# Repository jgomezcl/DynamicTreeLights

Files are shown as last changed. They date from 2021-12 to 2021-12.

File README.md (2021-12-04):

# Dynamic Tree Lights
Custom tree lights that react to changes in the environment lighting. Once a change is detected on an individual tree light it emits a white flash after a short delay followed by three more of random duration in random colors. These can also trigger nearby tree lights, so the flash propagates through the Christmas tree.

This project was inspired by CONSTELLACTION, an installation created by panGenerator for Copernicus Science Centre / Przemiany Festiwal 2013 (https://vimeo.com/76479685).

The PCBs are built around an Attiny84 microcontroller and require an ICSP to be programmed. I used an Arduino Nano with the sketch ArduinoISP.ino that can be found on the examples of the Arduino IDE.

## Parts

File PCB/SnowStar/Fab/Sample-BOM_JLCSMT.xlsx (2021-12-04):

Comment | Designator | Footprint | JLCPCB Part #（optional）
100n | C1 | Capacitor_SMD:C_0603_1608Metric | C14663
100n | C2 | Capacitor_SMD:C_0603_1608Metric | C14663
100n | C3 | Capacitor_SMD:C_0603_1608Metric | C14663
100n | C4 | Capacitor_SMD:C_0603_1608Metric | C14663
100n | C5 | Capacitor_SMD:C_0603_1608Metric | C14663
100n | C6 | Capacitor_SMD:C_0603_1608Metric | C14663
TX1812LB | D1 | SnowStar:LED_TX1812LB_TC2528RGB_2,4x2,7mm | C784561
TX1812LB | D2 | SnowStar:LED_TX1812LB_TC2528RGB_2,4x2,7mm | C784561
TX1812LB | D3 | SnowStar:LED_TX1812LB_TC2528RGB_2,4x2,7mm | C784561
TX1812LB | D4 | SnowStar:LED_TX1812LB_TC2528RGB_2,4x2,7mm | C784561
TX1812LB | D5 | SnowStar:LED_TX1812LB_TC2528RGB_2,4x2,7mm | C784561
TX1812LB | D6 | SnowStar:LED_TX1812LB_TC2528RGB_2,4x2,7mm | C784561
ICSP | J1 | Connector_PinHeader_2,54mm:PinHeader_2x03_P2,54mm_Vertical
Pow | J2 | Connector_PinHeader_2,54mm:PinHeader_1x02_P2,54mm_Vertical
Pow | J3 | Connector_PinHeader_2,54mm:PinHeader_1x02_P2,54mm_Vertical
SolderJumper_2_Open | JP1 | Jumper:SolderJumper-2_P1,3mm_Open_Pad1,0x1,5mm
10k | R1 | Resistor_SMD:R_0603_1608Metric | C25804
10k | R2 | Resistor_SMD:R_0603_1608Metric | C25804
10k | R3 | Resistor_SMD:R_0603_1608Metric | C25804
R_PHOTO | R4 | OptoDevice:R_LDR_5,1x4,3mm_P3,4mm_Vertical
R_PHOTO | R5 | OptoDevice:R_LDR_5,1x4,3mm_P3,4mm_Vertical
R_PHOTO | R6 | OptoDevice:R_LDR_5,1x4,3mm_P3,4mm_Vertical
10k | R7 | Resistor_SMD:R_0603_1608Metric | C25804
10k | R8 | Resistor_SMD:R_0603_1608Metric | C25804
ATtiny84-20SSU | U1 | Package_SO:SOIC-14_3,9x8,7mm_P1,27mm

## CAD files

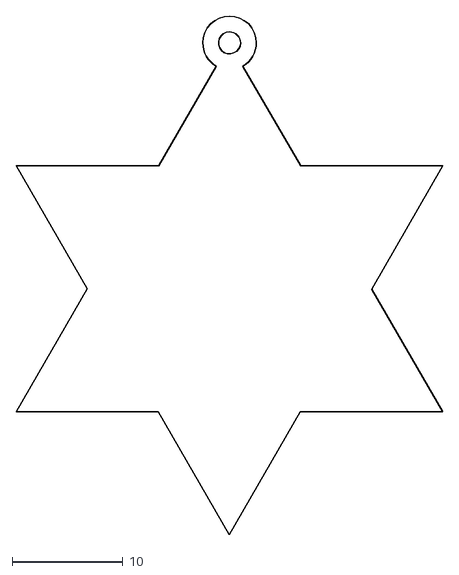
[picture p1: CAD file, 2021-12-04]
PCB/Drawings/SnowStarOutline.dxf
38.5 x 46.9

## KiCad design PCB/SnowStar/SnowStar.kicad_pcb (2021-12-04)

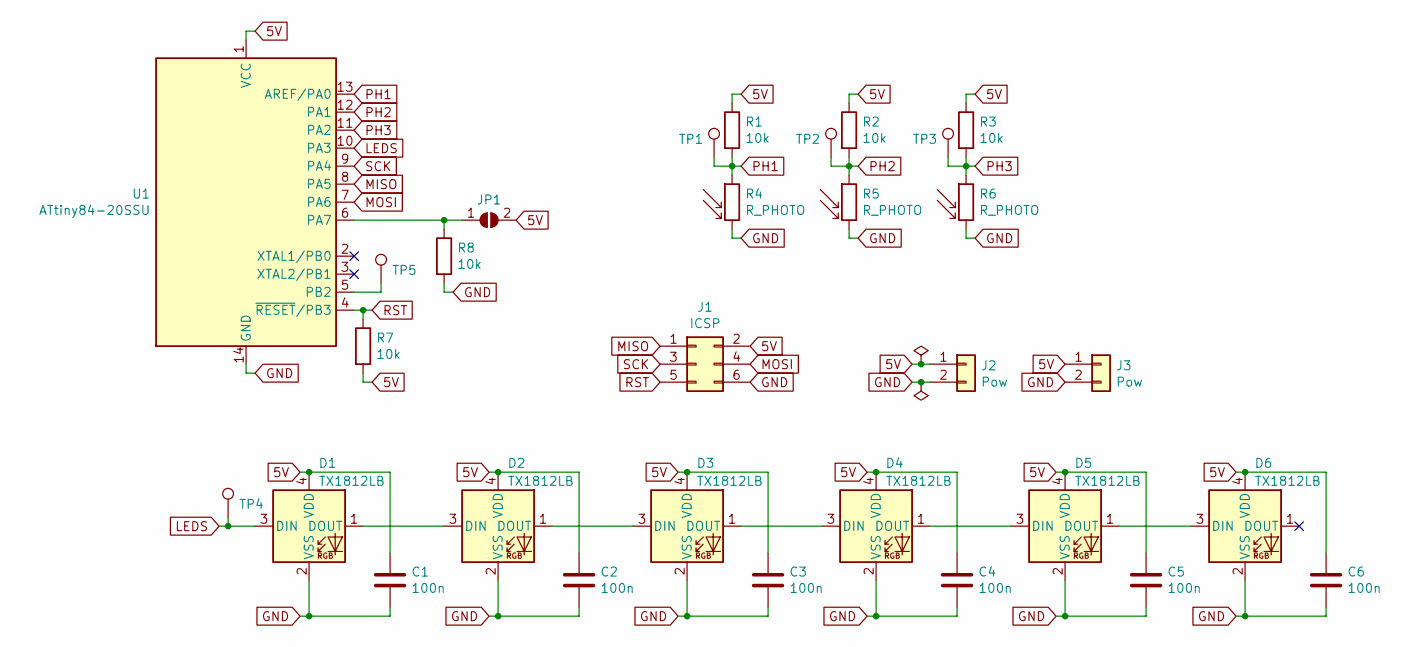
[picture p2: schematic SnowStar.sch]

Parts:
C1, C2, C3, C4, C5, C6: 100n; C_0603_1608Metric; LCSC Part # C14663
D1, D2, D3, D4, D5, D6: TX1812LB; LED_TX1812LB_TC2528RGB_2.4x2.7mm; LCSC Part # C784561
J1: ICSP; PinHeader_2x03_P2.54mm_Vertical
J2, J3: Pow; PinHeader_1x02_P2.54mm_Vertical
JP1: SolderJumper_2_Open; SolderJumper-2_P1.3mm_Open_Pad1.0x1.5mm
R1, R2, R3, R7, R8: 10k; R_0603_1608Metric; LCSC Part # C25804
R4, R5, R6: R_PHOTO; R_LDR_5.1x4.3mm_P3.4mm_Vertical
TP1, TP2, TP3, TP4, TP5: TestPoint; TestPoint_Pad_D1.5mm
U1: ATtiny84-20SSU; SOIC-14_3.9x8.7mm_P1.27mm

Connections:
5V: C1.1, C2.1, C3.1, C4.1, C5.1, C6.1, D1.4 (VDD), D2.4 (VDD), D3.4 (VDD), D4.4 (VDD), D5.4 (VDD), D6.4 (VDD), J1.2, J2.1, J3.1, JP1.2 (B), R1.1, R2.1, R3.1, R7.2, U1.1 (VCC)
GND: C1.2, C2.2, C3.2, C4.2, C5.2, C6.2, D1.2 (VSS), D2.2 (VSS), D3.2 (VSS), D4.2 (VSS), D5.2 (VSS), D6.2 (VSS), J1.6, J2.2, J3.2, R4.2, R5.2, R6.2, R8.2, U1.14 (GND)
LEDS: D1.3 (DIN), TP4.1, U1.10 (PA3)
MISO: J1.1, U1.8 (PA5)
MOSI: J1.4, U1.7 (PA6)
unnamed: D1.1 (DOUT), D2.3 (DIN)
unnamed: D2.1 (DOUT), D3.3 (DIN)
unnamed: D3.1 (DOUT), D4.3 (DIN)
unnamed: D4.1 (DOUT), D5.3 (DIN)
unnamed: D5.1 (DOUT), D6.3 (DIN)
unnamed: JP1.1 (A), R8.1, U1.6 (PA7)
unnamed: TP5.1, U1.5 (PB2)
PH1: R1.2, R4.1, TP1.1, U1.13 (AREF/PA0)
PH2: R2.2, R5.1, TP2.1, U1.12 (PA1)
PH3: R3.2, R6.1, TP3.1, U1.11 (PA2)
RST: J1.5, R7.1, U1.4 (~RESET~/PB3)
SCK: J1.3, U1.9 (PA4)

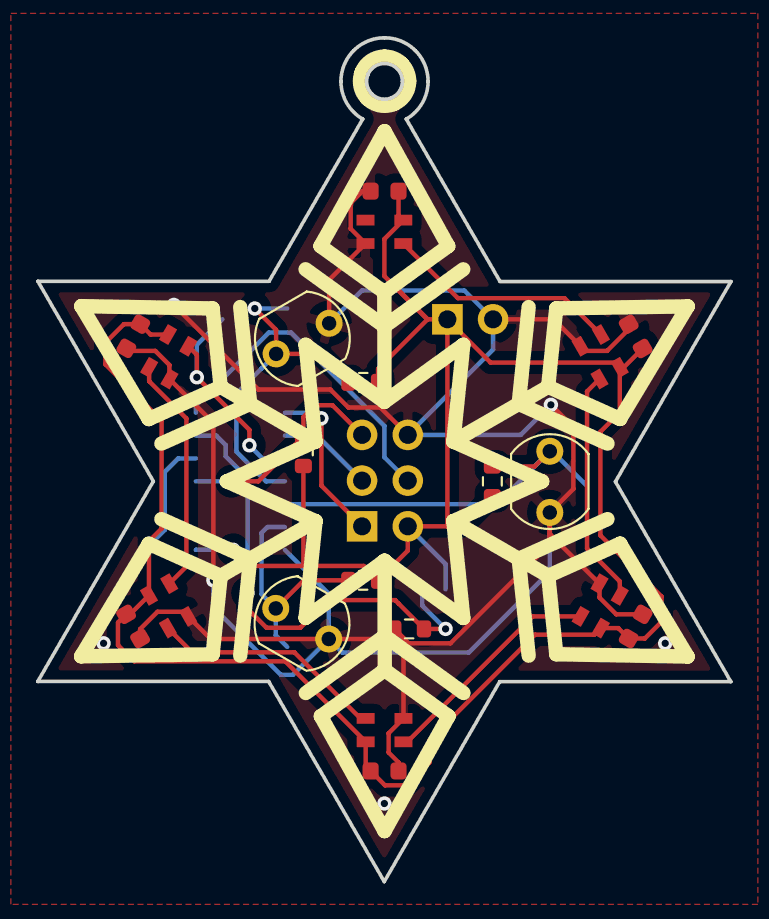
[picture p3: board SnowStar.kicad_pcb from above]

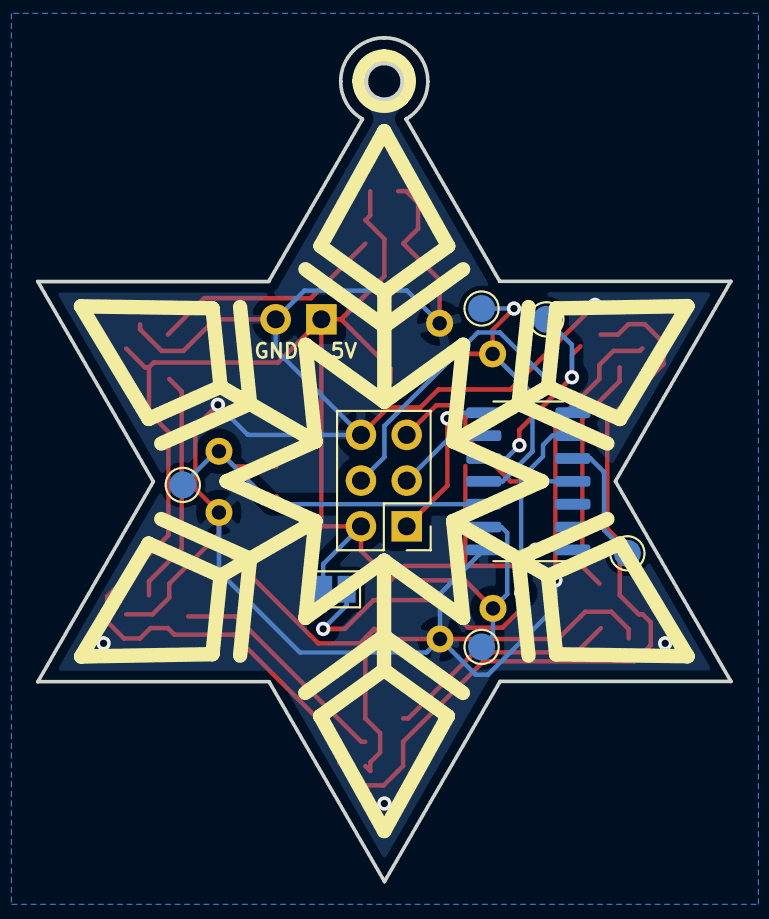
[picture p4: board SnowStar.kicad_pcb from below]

Board: 2 copper layers, 38.5 x 46.9 mm, 29 parts (8 on the bottom side), 17 nets.

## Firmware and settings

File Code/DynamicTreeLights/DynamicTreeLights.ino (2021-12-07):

/* DynamicTreeLights.ino

    04/12/2021
    Tested on an Attiny84
    The internal clock must be set to 8 MHz
*/

#include <WS2812.h>

/* Sensitivity configuration */
#define BUFSIZE 50
#define UPDATE_PERIOD 20
#define SENS_TRESHOLD 15

/* White color */
#define COLOR_R 255
#define COLOR_G 180
#define COLOR_B 70

/* Pins configuration */
#define LED_NUM 6
#define LED_PIN A3

#define LSENSOR_1 A1
#define LSENSOR_2 A0
#define LSENSOR_3 A2

#define SPONTANEOUS_TRIGGER       // Comment this line to avoid spontaneous blinks
#define PROBABILITY 20            // Probability of a spontaneous blink will be 1 divided by this number
#define SPONTANEOUS_PERIOD 10000  // Spontaneus probability will be checked with this periodicity (in ms)

//#define DEBUG   // To adjust the algorithm on a UNO

typedef struct circularBuffer
{
  int data[BUFSIZE];
  int pos;
  int validData;
} circularBuffer;

circularBuffer buf1, buf2, buf3;
unsigned long lastUpdate = 0;

WS2812 LEDS(LED_NUM);

#ifdef SPONTANEOUS_TRIGGER
uint16_t spontaneousCnt = 0;
#endif

void setup()
{

#ifdef DEBUG
  Serial.begin(9600);
  pinMode(LED_BUILTIN, OUTPUT);
#endif

  LEDS.setOutput(LED_PIN);

  setAllLeds(0, 0, 0);
  syncLeds();

  delay(400);

  delayedBlink();
}

void loop()
{
  if (millis() - lastUpdate > UPDATE_PERIOD)
  {
    lastUpdate += UPDATE_PERIOD;

    int newValue1 = analogRead(LSENSOR_1);
    int newValue2 = analogRead(LSENSOR_2);
    int newValue3 = analogRead(LSENSOR_3);

    addToBuffer(newValue1, &buf1);
    addToBuffer(newValue2, &buf2);
    addToBuffer(newValue3, &buf3);

    if (isDataValid(&buf1))
    {

#ifdef DEBUG
      Serial.print(getMean(&buf1));
      Serial.print(",");
      Serial.println(newValue1);
#endif

      if (newValue1 < getMean(&buf1) - SENS_TRESHOLD)
      {
        delayedBlink();
      }
      else if (newValue2 < getMean(&buf2) - SENS_TRESHOLD)
      {
        delayedBlink();
      }
      else if (newValue3 < getMean(&buf3) - SENS_TRESHOLD)
      {
        delayedBlink();
      }
      else
      {
#ifdef SPONTANEOUS_TRIGGER
        spontaneousCnt++;
        if (spontaneousCnt >= SPONTANEOUS_PERIOD / UPDATE_PERIOD)
        {
          spontaneousCnt = 0;
          if (random(0, PROBABILITY) <= 0)
          {
            delayedBlink();
          }
        }
#endif
      }
    }
  }
}

void addToBuffer(int newValue, circularBuffer *buf)
{
  buf->data[buf->pos] = newValue;

  buf->pos++;
  if (buf->pos >= BUFSIZE)
    buf->pos = 0;

  buf->validData++;
  if (buf->validData >= BUFSIZE)
    buf->validData = BUFSIZE;
}

bool isDataValid(circularBuffer *buf)
{
  if (buf->validData < BUFSIZE)
    return false;

  return true;
}

int getMean(circularBuffer *buf)
{
  unsigned long result = 0;
  for (int i = 0; i < BUFSIZE; i++)
  {
    result += buf->data[i];
  }

  result /= BUFSIZE;

  return (int)result;
}

void syncLeds()
{
  LEDS.sync();
  delay(1); // Without this delay consecutive calls to sync() are ignored
}

void delayedBlink()
{
  delay(200);

  int val = 255;

  for (int i = val; i >= 0; i = i / 2 - 1)
  {
    setAllLeds((i * COLOR_R) / 255, (i * COLOR_G) / 255, (i * COLOR_B) / 255);
    syncLeds();
    delay(30);
  }

  setAllLeds(0, 0, 0);
  syncLeds();

  randomPattern2();
  delay(500);

  buf1.validData = 0;
  buf2.validData = 0;
  buf3.validData = 0;
}

void setLed(int pos, int red, int green, int blue)
{
  cRGB color;
  color.r = red;
  color.g = green;
  color.b = blue;

  LEDS.set_crgb_at(pos, color);
}

void setAllLeds(int red, int green, int blue)
{
  for (int i = 0; i < LED_NUM; i++)
  {
    setLed(i, red, green, blue);
  }
}

void startPattern()
{
  int seq[LED_NUM];

  for (int i = 0; i < LED_NUM; i++)
  {
    seq[i] = random(0, LED_NUM);
  }

  for (int j = 0; j < LED_NUM; j++)
  {
    for (int i = 255; i >= 0; i = i / 2 - 1)
    {
      setLed(seq[j], (i * COLOR_R) / 255, (i * COLOR_G) / 255, (i * COLOR_B) / 255);
      syncLeds();
      delay(30);
    }
  }
}

void randomPattern1()
{
  int r, g, b;

  int seq[LED_NUM];

  for (int i = 0; i < LED_NUM; i++)
  {
    seq[i] = random(0, LED_NUM);
  }

  for (int j = 0; j < LED_NUM; j++)
  {
    r = random(0, 256);
    g = random(0, 256);
    b = random(0, 256);

    for (int i = 255; i >= 0; i = i / 2 - 1)
    {
      setLed(seq[j], (i * r) / 255, (i * g) / 255, (i * b) / 255);
      syncLeds();
      delay(30);
    }
  }
}

void randomPattern2()
{
  int r1, g1, b1;
  int r2, g2, b2;

  int seq[LED_NUM];

  seq[0] = random(0, LED_NUM);

  for (int i = 1; i < LED_NUM; i++)
  {
    do
    {
      seq[i] = random(0, LED_NUM);
    } while (seq[i] == seq[i - 1]);
  }

  int decaySpeed;

  for (int j = 0; j < LED_NUM / 2; j++)
  {
    r1 = random(0, 256);
    g1 = random(0, 256);
    b1 = random(0, 256);

    r2 = random(0, 256);
    g2 = random(0, 256);
    b2 = random(0, 256);

    decaySpeed = random(10, 40);

    for (int i = 255; i >= 0; i = i / 2 - 1)
    {
      setLed(seq[j * 2], (i * r1) / 255, (i * g1) / 255, (i * b1) / 255);
      setLed(seq[j * 2 + 1], (i * r2) / 255, (i * g2) / 255, (i * b2) / 255);
      syncLeds();
      delay(decaySpeed);
    }
  }
}
